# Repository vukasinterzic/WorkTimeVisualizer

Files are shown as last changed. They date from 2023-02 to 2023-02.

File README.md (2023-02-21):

# Work Time Visualizer

I made this device to help me track and reduce the number of hours I spend working every day. Working over multiple time zones means that I can’t really rely on the time of the day. And software tools didn’t work for me, I needed something visual.

****This is a tool for all my workaholic friends out there.****

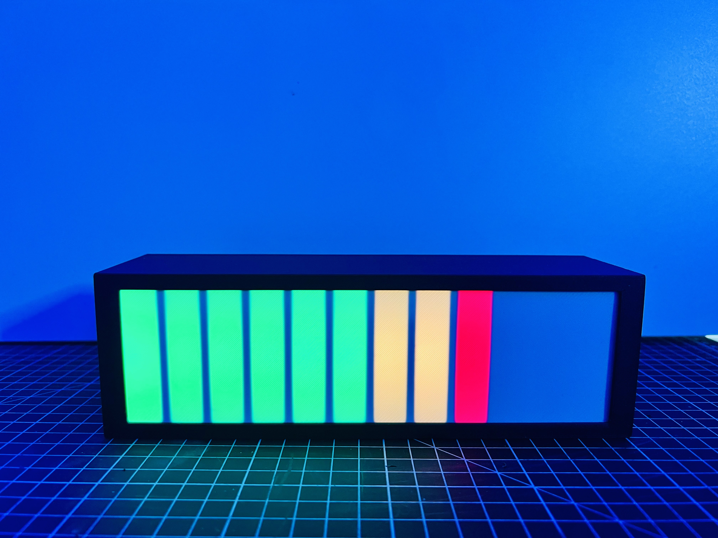
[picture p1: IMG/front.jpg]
Work Time Visualizer


12 lights for 12 hours. Large enough to be visible but not distracting.

IT people make jokes that one 24h day has 3 MDs of work. If I still end up working more than 12 hours then this device is not working.

## Light configuration:

1-6 – Green lights – keep working

7-8 – Orange – time is running out, finish things and plan for tomorrow

9-10 – Red – stop working

11-12 – flashing RED – seriously, stop working

12+ All lights are flashing red. Self-destruction in progress.

Animation

## Other functionality:
-	Every hour is saved to EEPROM and retrieved when turned back on.
-	Progress can be manually adjusted with a push button on the back.
-   After 13 hours is reached, automatic counting will not continue and it will end there. Reset can be done by pressing the button.

## Recommendations for time tracking:

The idea is to track real time spent working, not just time of the day. Connect device to a cable with a switch, or even better to a smart plug. You can turn it off if you make breaks from work during the day.

### Here is my setup:
-	Connected to a smart plug.
-	I have a routine to start working that I activate with the voice/Stream Deck. I added this plug to the routine and it will be turned on.
-	I have IFTTT integration and a toggle button on my Stream Deck so I can turn it off and back on with a button whenever I’m taking a break from work.
-	I have a routine to end work in the evening, this will turn it off.

## 3D Printing:
No supports needed, infill as you wish.

Front white diffuser can be replaced with a sheet of paper for very clean look. Or thin black acrylic diffuser for stealth look.

Back LED Cover has holders to fit prototype  PCB board of 10cm length (this one: https://amzn.to/3XEdoul). You can print a version without PCB holder and figure out a different way to mount your electronic (hot-glue?) 

Back box cover is provided in versions with and without hole for the push button. Since the part is very thin, you can easily drill the hole to fit your button location.

You can download STL files from ***Printables***: https://www.printables.com/model/400426-work-time-visualizer

## Other hardware:
Apart from the 3d printed parts, the following is needed:
-	Smaller Arduino board with EEPROM. Some boards such as Seeeduino Xiao don’t have EEPROM and you will need to use emulator instead. I used ATTINY85 - https://amzn.to/3K7cdAL

-	12 pixels of individually addressable 5V LED strip or individual NeoPixel LEDs. Files fit NeoPixel strip WS2812B with 60 pixel/meter - https://amzn.to/3YAC5Jw

-	5V power adapter and a cable. You can use 5V USB port on your Arduino, or you can cut USB cable and solder + and - directly, or use 5mm female connector as I did.
-	10K resistor - https://amzn.to/40Z81Jd
-	Push Button. For example this one: https://amzn.to/3IoVOX8

## Electronic Circuit Diagram:

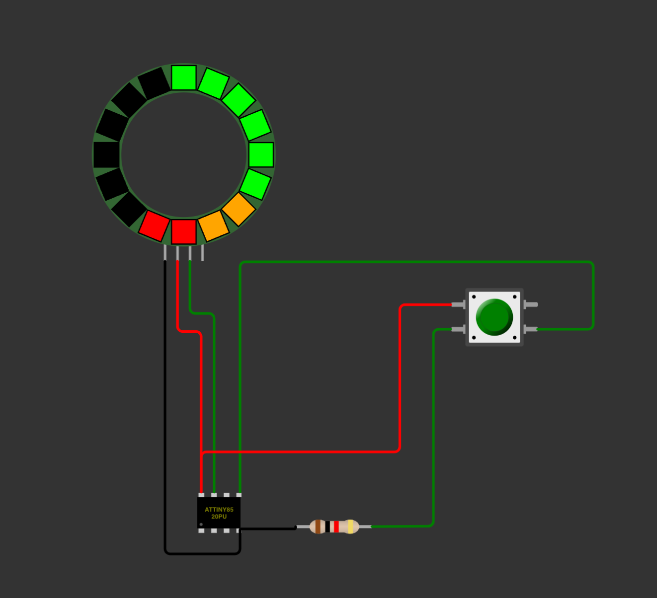
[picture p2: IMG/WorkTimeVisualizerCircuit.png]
Circuit Diagram


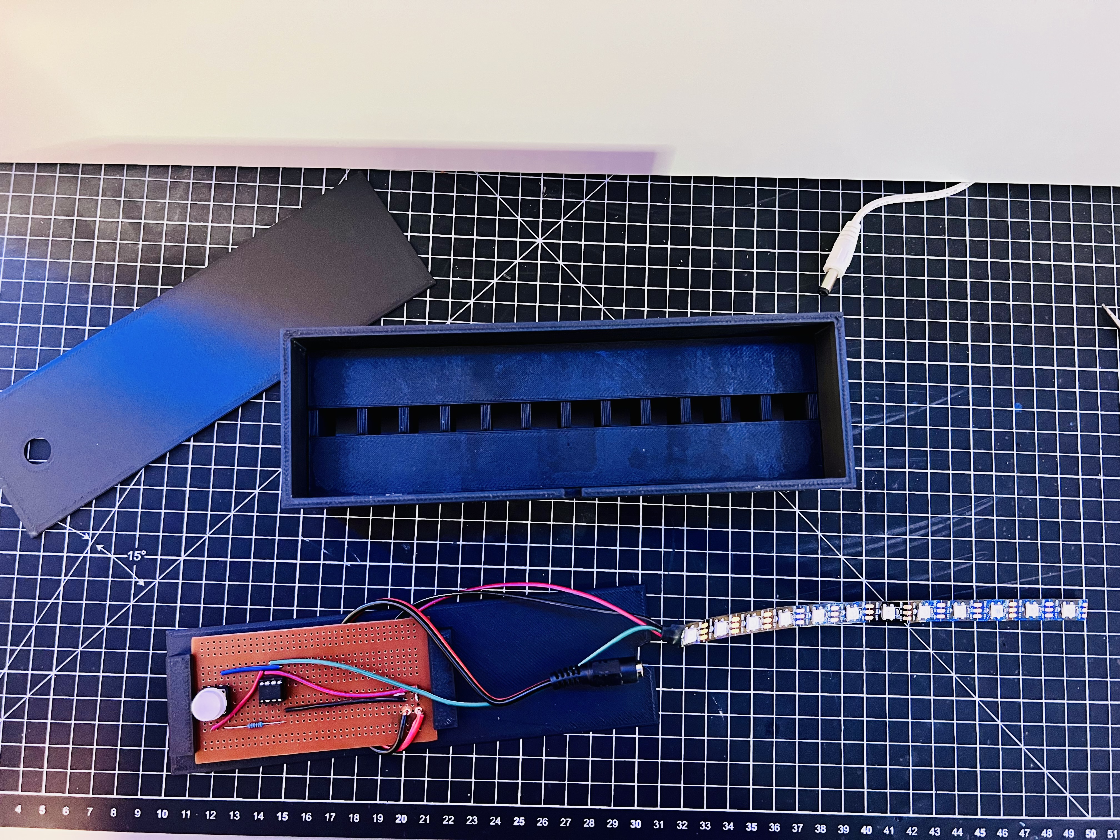
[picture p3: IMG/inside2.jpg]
Inside Work Time Visualizer


# Known issues:
* ISS1: button sometimes register multiple clicks. This can probably be fixed by software debounce.
* ISS2: if turned off, time since last full hour will be lost. One hour timer will start from 0 after it is turned back on.
* ISS3: no reset function, need to go up to 13 to reset (using button)
* ISS4: This is not a bug it's a feature! I did not add EEPROM write after making changes with button. Therefore if button is pressed to set lights, and then turned off, that state will not be saved. Last saved change will be from when one hour passed. This is because EEPROM memory has a limited number of rewrites and holding button (or removing it completely) will generate a lot of fast changes. Therefore I did not add EEPROM write there to protect the accidental memory demaging.

# Version 2 Ideas:

* Use Real Time Clock to improve accuracy, fix issues with loosing time. Also to automatic reset next day. I used the full board with a lot of space left on it to fit the RTC.
* Use better button and place it on top of the case, this is not optimal location and it can be hard to reach
* Use Arduino board with USB-C port or a famale USB-C connector inside the case
* Use black acrylic as diffuser, so it is black and less visible when not in lit
* Connect to the Internet and keep daily history on GitHub, Calendar etc.

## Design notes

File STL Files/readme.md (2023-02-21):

STL files moved to Printables: 

https://www.printables.com/model/400426-work-time-visualizer

(it's easier to maintain files at one place )

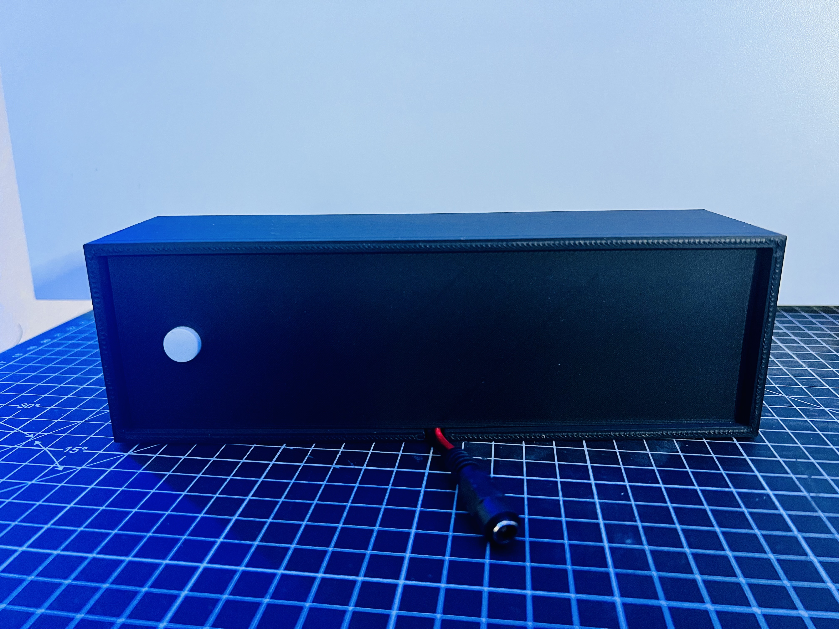
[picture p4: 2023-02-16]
IMG/back.jpg

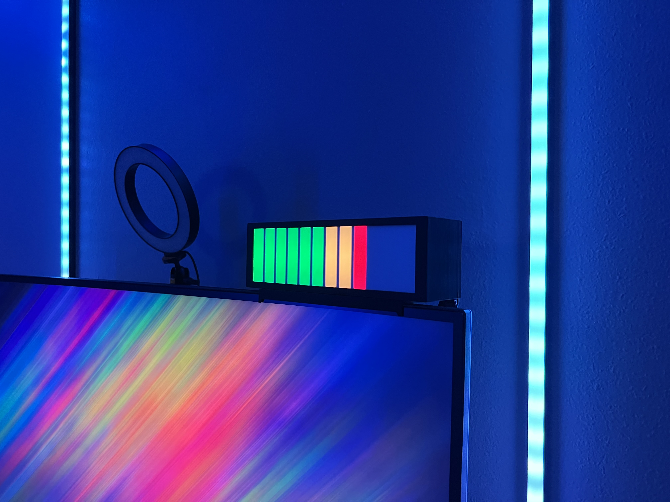
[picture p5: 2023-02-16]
IMG/monitor.jpg

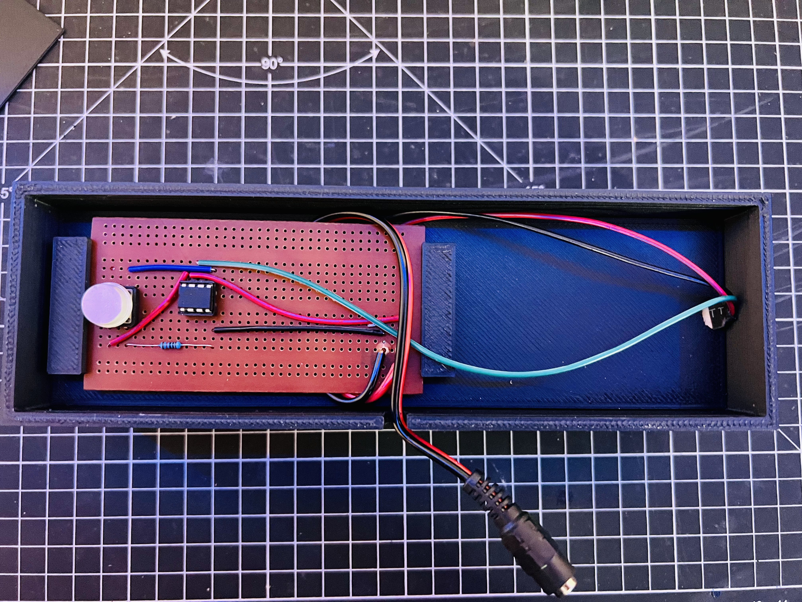
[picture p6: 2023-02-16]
IMG/inside1.jpg

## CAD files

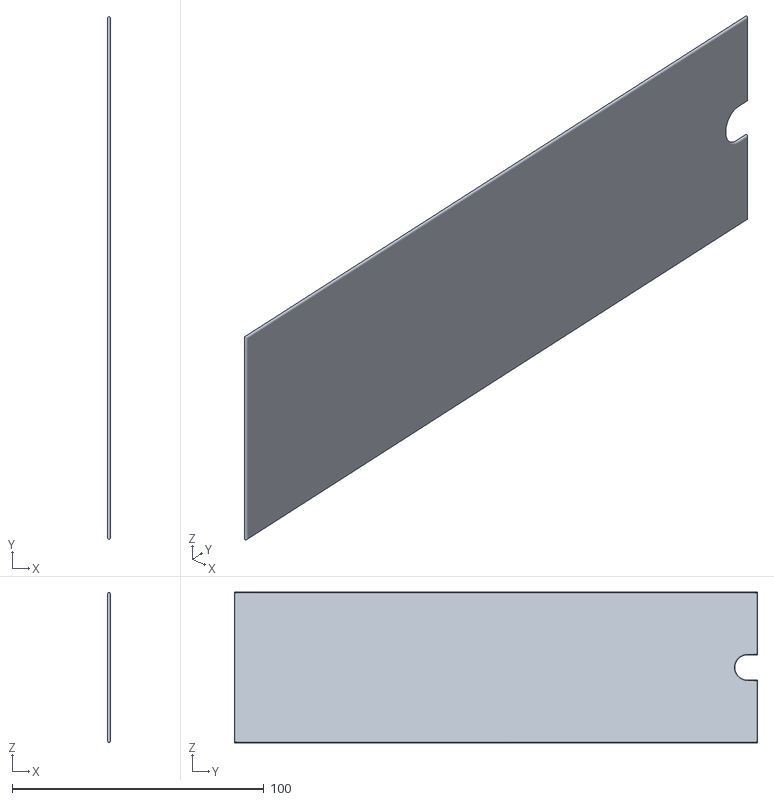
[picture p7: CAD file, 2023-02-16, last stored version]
STL Files/WorkTimeVisualizer-LED Back Cover (no PCB mount).stl
1.00 x 207.8 x 59.8

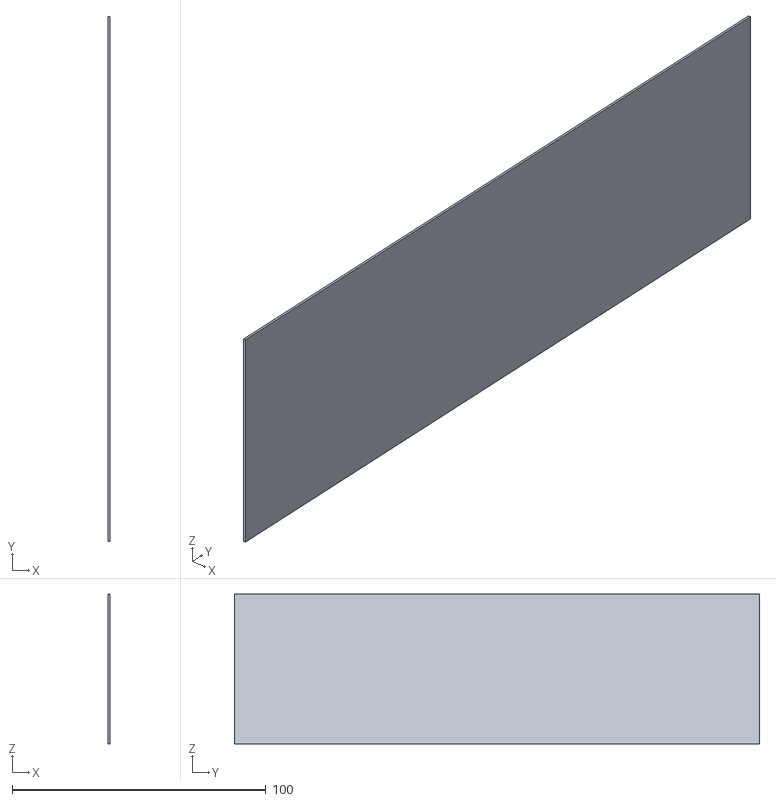
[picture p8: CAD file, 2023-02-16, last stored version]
STL Files/WorkTimeVisualizer-Diffuser-v1.stl
0.6 x 207.0 x 59.0

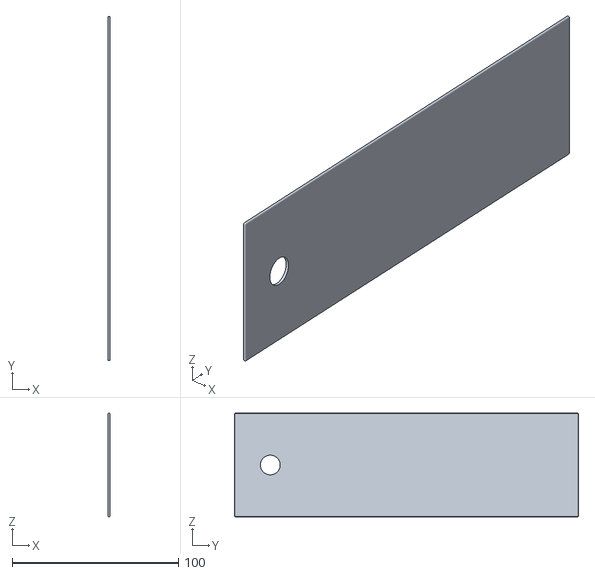
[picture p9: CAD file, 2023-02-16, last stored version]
STL Files/WorkTimeVisualizer-Box Back Cover.stl
1.20 x 207.0 x 62.5

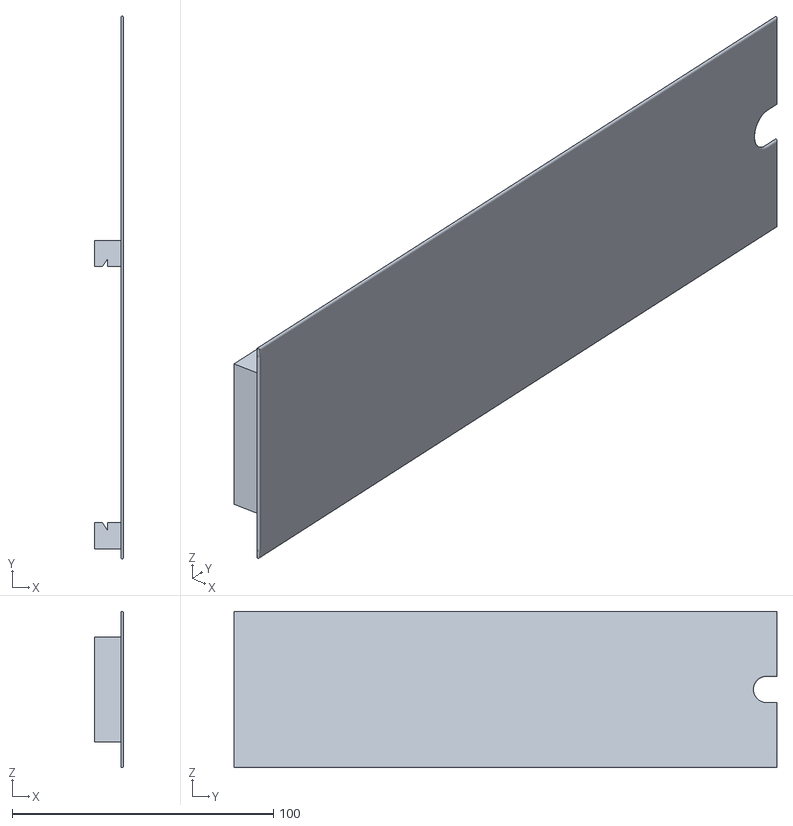
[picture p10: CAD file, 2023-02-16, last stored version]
STL Files/WorkTimeVisualizer-LED Back Cover-v2.stl
11.0 x 207.8 x 59.8

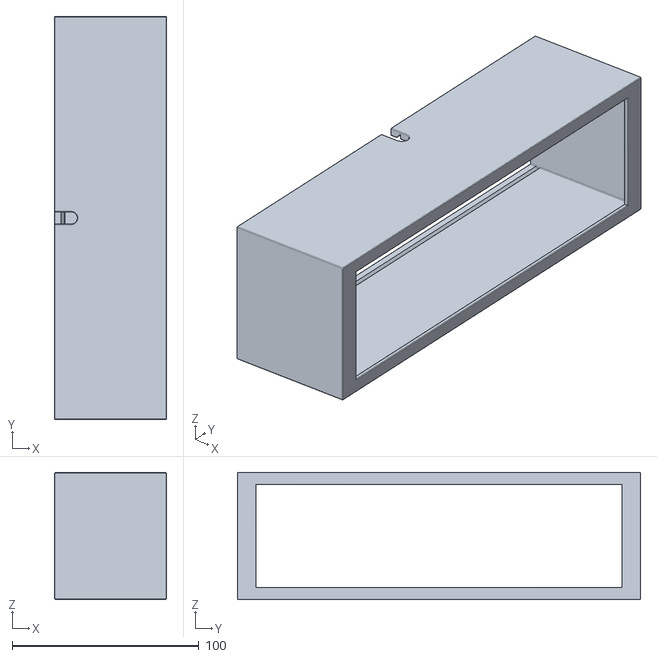
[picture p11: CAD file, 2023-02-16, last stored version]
STL Files/WorkTimeVisualizer-Box-v1.stl
60.0 x 216.0 x 68.0

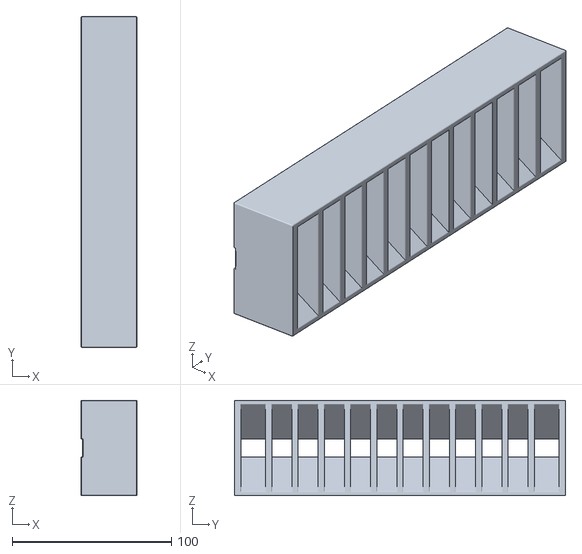
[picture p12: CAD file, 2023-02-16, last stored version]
STL Files/WorkTimeVisualizer-LED Divider-v1.stl
35.0 x 208.0 x 60.0

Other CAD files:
STL Files/WorkTimeVisualizer-Box Back Cover (no button hole).stl

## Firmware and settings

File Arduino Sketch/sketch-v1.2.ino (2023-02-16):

/*
Version: 1.2
Author: Vukasin Terzic
Description:


Requirements:
this is for chip with eeprom
Seeeduino doesn't have it so this can't be used!


*/

  
  
  #include <Adafruit_NeoPixel.h>
  #include <EEPROM.h>

  #ifdef __AVR__
   #include <avr/power.h>
  #endif
  
  
    // Read value from EEPROM
    int EEPROMaddress = 1; // address - total 256 bytes
    int WorkHours = EEPROM.read(EEPROMaddress); //retrieves value for address
  
  // Which pin on the Arduino is connected to the NeoPixels?
  #define LED_PIN     2

  // How many NeoPixels are attached to the Arduino?
  #define LED_COUNT   16

  // Button configuration
  #define BUTTON_PIN  0
  byte currentState;     // the current reading from the input pin
  
  // Declare our NeoPixel strip object:
  Adafruit_NeoPixel strip(LED_COUNT, LED_PIN, NEO_GRB + NEO_KHZ800);


  //Millis for counting hours:
  unsigned long startMillis;
  unsigned long currentMillis;
  const unsigned long period = 3600000; //1h = 3600 000 ms, 1 minute is 60000 ms, 1s = 1000 ms

void setup() {
  // put your setup code here, to run once:
  
  //start counting ms
  startMillis = millis(); //initial start time


  //Set WorkHours value and save it to EEPROM:
  if ( WorkHours >= 12 ) {
    
    WorkHours = 0;
    delay(200);
    EEPROM.update(EEPROMaddress, WorkHours);
    delay(1000);
    
  }

    #if defined(__AVR_ATtiny85__) && (F_CPU == 16000000)
      clock_prescale_set(clock_div_1);
    #endif

  strip.begin();           // INITIALIZE NeoPixel strip object (REQUIRED)
  strip.show();            // Turn OFF all pixels ASAP
//  strip.setBrightness(50); // Set BRIGHTNESS to about 1/5 (max = 255)

//button config:
  pinMode(BUTTON_PIN, INPUT);
}


void loop() {

  currentMillis = millis();  //get the current time passed
  
  if (currentMillis - startMillis >= period) { //test whether the period has elapsed

    WorkHours++;
    delay(200);

    if (WorkHours >= 13) {

        WorkHours = 13;

    } else {

      //This part will run only once when <period value reached> AND <if WorkHours less than 13 >. In theory this runs only once every hour. In theory :D
      
      EEPROM.update(EEPROMaddress, WorkHours);
      delay(1000);

    }
    
    startMillis = millis(); //start again
  }

  // read the state of the switch/button:
  currentState = digitalRead(BUTTON_PIN);

if (currentState == HIGH) {
      WorkHours++;
      startMillis = millis(); //start again

      if (WorkHours > 13) {
        WorkHours = 0;
      } //FIXME: it is not writing WorkHours value to EEPROM. This can be added here as another Else if needed.
}

delay(100);

// set lights depending on WorkHours value:

  if (WorkHours == 1) {

    strip.setPixelColor(0,0,255,0,250);
    strip.show();
    
  } else if (WorkHours == 2) {
    
    strip.setPixelColor(0,0,255,0,250);
    strip.setPixelColor(1,0,255,0,250);
    strip.show();
  
  } else if (WorkHours == 3) {

    strip.setPixelColor(0,0,255,0,250);
    strip.setPixelColor(1,0,255,0,250);
    strip.setPixelColor(2,0,255,0,250);
    strip.show();
  
  } else if (WorkHours == 4) {

    strip.setPixelColor(0,0,255,0,250);
    strip.setPixelColor(1,0,255,0,250);
    strip.setPixelColor(2,0,255,0,250);
    strip.setPixelColor(3,0,255,0,250);
    strip.show();
  
  } else if (WorkHours == 5) {

    strip.setPixelColor(0,0,255,0,250);
    strip.setPixelColor(1,0,255,0,250);
    strip.setPixelColor(2,0,255,0,250);
    strip.setPixelColor(3,0,255,0,250);
    strip.setPixelColor(4,0,255,0,250);
    strip.show();
  
  } else if (WorkHours == 6) {

    strip.setPixelColor(0,0,255,0,250);
    strip.setPixelColor(1,0,255,0,250);
    strip.setPixelColor(2,0,255,0,250);
    strip.setPixelColor(3,0,255,0,250);
    strip.setPixelColor(4,0,255,0,250);
    strip.setPixelColor(5,0,255,0,250);
    strip.show();
  
  } else if (WorkHours == 7) {

    strip.setPixelColor(0,0,255,0,250);
    strip.setPixelColor(1,0,255,0,250);
    strip.setPixelColor(2,0,255,0,250);
    strip.setPixelColor(3,0,255,0,250);
    strip.setPixelColor(4,0,255,0,250);
    strip.setPixelColor(5,0,255,0,250);
    strip.setPixelColor(6,255,165,0,250);
    strip.show();
  
  } else if (WorkHours == 8) {

    strip.setPixelColor(0,0,255,0,250);
    strip.setPixelColor(1,0,255,0,250);
    strip.setPixelColor(2,0,255,0,250);
    strip.setPixelColor(3,0,255,0,250);
    strip.setPixelColor(4,0,255,0,250);
    strip.setPixelColor(5,0,255,0,250);
    strip.setPixelColor(6,255,165,0,250);
    strip.setPixelColor(7,255,165,0,250);
    strip.show();
  
  } else if (WorkHours == 9) {

    strip.setPixelColor(0,0,255,0,250);
    strip.setPixelColor(1,0,255,0,250);
    strip.setPixelColor(2,0,255,0,250);
    strip.setPixelColor(3,0,255,0,250);
    strip.setPixelColor(4,0,255,0,250);
    strip.setPixelColor(5,0,255,0,250);
    strip.setPixelColor(6,255,165,0,250);
    strip.setPixelColor(7,255,165,0,250);
    strip.setPixelColor(8,255,0,0,250);
    strip.show();
  
  } else if (WorkHours == 10) {

    strip.setPixelColor(0,0,255,0,250);
    strip.setPixelColor(1,0,255,0,250);
    strip.setPixelColor(2,0,255,0,250);
    strip.setPixelColor(3,0,255,0,250);
    strip.setPixelColor(4,0,255,0,250);
    strip.setPixelColor(5,0,255,0,250);
    strip.setPixelColor(6,255,165,0,250);
    strip.setPixelColor(7,255,165,0,250);
    strip.setPixelColor(8,255,0,0,250);
    strip.setPixelColor(9,255,0,0,250);
    strip.show();
  
  } else if (WorkHours == 11) {

    strip.setPixelColor(0,0,255,0,250);
    strip.setPixelColor(1,0,255,0,250);
    strip.setPixelColor(2,0,255,0,250);
    strip.setPixelColor(3,0,255,0,250);
    strip.setPixelColor(4,0,255,0,250);
    strip.setPixelColor(5,0,255,0,250);
    strip.setPixelColor(6,255,165,0,250);
    strip.setPixelColor(7,255,165,0,250);
    strip.setPixelColor(8,255,0,0,250);
    strip.setPixelColor(9,255,0,0,250);
    strip.show();
    
    strip.setPixelColor(10,139,0,0,250);
    strip.show();
    delay(600);
    strip.setPixelColor(10,0,0,0,250);
    strip.show();
    delay(600);
  
  } else if (WorkHours == 12) {

    strip.setPixelColor(0,0,255,0,250);
    strip.setPixelColor(1,0,255,0,250);
    strip.setPixelColor(2,0,255,0,250);
    strip.setPixelColor(3,0,255,0,250);
    strip.setPixelColor(4,0,255,0,250);
    strip.setPixelColor(5,0,255,0,250);
    strip.setPixelColor(6,255,165,0,250);
    strip.setPixelColor(7,255,165,0,250);
    strip.setPixelColor(8,255,0,0,250);
    strip.setPixelColor(9,255,0,0,250);
    strip.show();
    
    strip.setPixelColor(10,139,0,0,250);
    strip.setPixelColor(11,139,0,0,250);
    strip.show();
    delay(600);
    strip.setPixelColor(10,0,0,0,250);
    strip.setPixelColor(11,0,0,0,250);
    strip.show();
    delay(600);
  
  } else if (WorkHours == 13) {

    for(int i=0; i<12; i++) {
    strip.setPixelColor(i,250,0,0,250);
    strip.show();
    delay(30);
    }

    for(int i=0; i<12; i++) {
    strip.setPixelColor(i,0,0,0,0);
    strip.show();
    delay(30);
    }

/* circle with blue light

    for(int i=0; i<12; i++) {
    strip.setPixelColor(i,0,0,250,250);
    strip.show();
    delay(30);
    }

    for(int i=0; i<12; i++) {
    strip.setPixelColor(i,0,0,0,0);
    strip.show();
    delay(30);
    }
*/

  } else {

    colorWipe(strip.Color(0, 0, 0), 0); // off
  
  }
  
} //end of loop


//individual functions:

void colorWipe(uint32_t color, int wait) {
  for(int i=0; i<strip.numPixels(); i++) { // For each pixel in strip...
    strip.setPixelColor(i, color);         //  Set pixel's color (in RAM)
    strip.show();                          //  Update strip to match
    delay(wait);                           //  Pause for a moment
  }
}

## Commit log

2023-02-16 fixed brackets for image
2023-02-16 files added
    [WorkTimeVisualizer-Box Back Cover (no button hole).stl, WorkTimeVisualizer-Box Back Cover.stl, WorkTimeVisualizer-Box-v1.stl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]
2023-02-21 deleted STL files
    [WorkTimeVisualizer-Box Back Cover (no button hole).stl, WorkTimeVisualizer-Box Back Cover.stl, WorkTimeVisualizer-Box-v1.stl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]
